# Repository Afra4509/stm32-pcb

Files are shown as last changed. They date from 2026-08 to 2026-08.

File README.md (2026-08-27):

# STM32F103 PCB Design

Repository: https://github.com/Afra4509/stm32-pcb

# Custom STM32F103C8T6 Bare-Chip Development Board

Proyek ini adalah desain custom board berbasis **STM32F103C8T6** yang disolder langsung pada PCB (bare-chip). Desain ini menggunakan template KiCad yang telah dikonfigurasi untuk power delivery, reset circuit, dan external oscillator.

## Fitur Utama Board
- **MCU**: STM32F103C8T6 (LQFP-48)
- **Regulator 3.3V**: LDO (Low Dropout) untuk konversi 5V dari USB/VIN ke 3.3V.
- **Decoupling**: 4x 100nF capacitor diletakkan sedekat mungkin dengan pin VDD, dan 10uF bulk capacitor.
- **Clock**: External Crystal 8MHz (atau 16MHz) + 2x 20pF load capacitors.
- **Bootloader**: Jumper/Switch BOOT0 dengan pull-down 10kΩ.
- **Programming**: 4-pin SWD header (3V3, SWDIO, SWCLK, GND).
- **Konektivitas**: Pin GPIO diekspos melalui header 2.54mm.

### 1. Mengganti USB Micro-B ke USB-C
Secara default, skematik ini menggunakan **USB Micro-B**. Untuk mengubahnya ke **USB-C**:
1. Buka `STM32F103_Custom.kicad_sch` di KiCad.
2. Hapus simbol USB Micro-B.
3. Tambahkan simbol `USB_C_Receptacle_USB2.0`.
4. Hubungkan pin VBUS ke 5V dan GND ke Ground.
5. Tambahkan **dua buah resistor 5.1kΩ**. Hubungkan CC1 ke GND dan CC2 ke GND (wajib agar power 5V keluar dari host).
6. Hubungkan pin D+ ke PA12 dan D- ke PA11. Pastikan Anda memiliki resistor pull-up 1.5kΩ di D+ jika menggunakan skema full-speed USB standar (STM32 tertentu butuh ini).

### 2. Menambahkan User LED
1. Tambahkan komponen LED dan Resistor (misal 1kΩ) pada skematik.
2. Hubungkan pin anoda LED ke 3.3V.
3. Hubungkan pin katoda ke resistor, lalu ke **PC13** pada STM32 (Active Low).
4. Berikan label "USER LED".

### 3. Menambahkan User Button
1. Tambahkan komponen Push Button (SPST).
2. Hubungkan satu sisi ke GND dan sisi lainnya ke **PA0**.
3. Tambahkan resistor pull-up eksternal 10kΩ ke 3.3V pada sisi PA0, atau gunakan pull-up internal MCU.
4. Berikan label "USER BUTTON".

### 4. Layout dan Routing (PCB Editor)
Buka file `STM32F103_Custom.kicad_pcb`:
- **Placement**: Pindahkan konektor USB-C yang baru, LED, dan Button ke tempat yang mudah diakses.
- **Routing**: Rutekan (track) jalur USB-C (D+ dan D- sebagai differential pair), serta jalur GPIO ke LED dan Button.
- **GND Plane**: Board ini menggunakan copper pour untuk GND Plane di layer bawah (B.Cu).
- **Silkscreen**: Tambahkan teks indikator untuk LED, Button, dan pin 3V3/5V/GND di area Silkscreen.

## Aturan Desain (DRC / ERC)
Sebelum mengirimkan ke manufaktur (seperti JLCPCB atau PCBWay):
- Jalankan **ERC (Electrical Rules Checker)** di Schematic Editor untuk memastikan tidak ada net yang melayang (floating).
- Jalankan **DRC (Design Rules Checker)** di PCB Editor.
- Pastikan clearance antara jalur memenuhi standar manufaktur (minimal 0.15mm atau 6 mils).

## Struktur File
- `STM32F103_Custom.kicad_pro` : File proyek utama.
- `STM32F103_Custom.kicad_sch` : File skematik.
- `STM32F103_Custom.kicad_pcb` : File layout PCB.

Terima kasih, dan selamat merakit board STM32 kustom Anda!

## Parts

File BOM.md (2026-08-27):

# Bill of Materials (BOM) - STM32F103 Custom Board

Berikut adalah daftar komponen (BOM) yang disarankan untuk merakit board ini. Anda dapat membeli komponen ini dari supplier seperti LCSC, DigiKey, Mouser, atau Tokopedia.

| Referensi | Komponen / Nilai | Footprint | Deskripsi |
| :--- | :--- | :--- | :--- |
| **U1** | **STM32F103C8T6** | LQFP-48 | Microcontroller ARM Cortex-M3 (Bare-Chip) |
| **U2** | **AMS1117-3.3** atau **AP2112K-3.3** | SOT-223 / SOT-23-5 | LDO Voltage Regulator (5V ke 3.3V) |
| **J1** | **USB-C Receptacle** | 16-pin / 6-pin | Power & Data Input (Data opsional) |
| **Y1** | **Crystal 8MHz** | SMD 5032 / HC49 | High-Speed External Clock (HSE) |
| **C1, C2** | **20pF** | 0603 / 0805 | Load Capacitor untuk Crystal Y1 |
| **C3, C4, C5, C6**| **100nF (0.1µF)** | 0603 / 0805 | Decoupling Capacitor (Dekat VDD/VDDA) |
| **C7** | **100nF (0.1µF)** | 0603 / 0805 | NRST Filter Capacitor |
| **C8, C9** | **10µF** | 0805 / 1206 | Input & Output Bulk Capacitor untuk LDO |
| **R1, R2** | **5.1kΩ** | 0603 / 0805 | Pull-down resistor untuk pin CC1 dan CC2 di USB-C |
| **R3** | **1.5kΩ** | 0603 / 0805 | Pull-up resistor untuk USB D+ (opsional/tergantung desain) |
| **R4, R5** | **10kΩ** | 0603 / 0805 | Pull-down untuk BOOT0 dan Pull-up untuk NRST/Button |
| **R6, R7** | **1kΩ - 2.2kΩ** | 0603 / 0805 | Current Limiting Resistor untuk LED |
| **LED1** | **LED Merah/Hijau** | 0603 / 0805 | Power Indicator LED |
| **LED2** | **LED Biru/Kuning** | 0603 / 0805 | User LED (Terhubung ke PC13) |
| **SW1** | **Push Button (SPST)**| SMD 3x4 / 6x6 | Reset Button |
| **SW2** | **Push Button (SPST)**| SMD 3x4 / 6x6 | User Button (Terhubung ke PA0) |
| **J2** | **Pin Header 1x4** | 2.54mm Pitch | SWD Programming Header (3V3, SWDIO, SWCLK, GND) |
| **J3, J4** | **Pin Header 1x20** | 2.54mm Pitch | GPIO Expansion Header |
| **J5** | **Pin Header 1x3** | 2.54mm Pitch | BOOT0 Selection Jumper |

## Catatan Perakitan
1. **Penyolderan MCU**: Solder IC STM32F103C8T6 terlebih dahulu menggunakan teknik drag soldering atau hot air. Perhatikan orientasi pin 1 (titik pada IC).
2. **Kapasitor Decoupling**: Tempatkan C3-C6 (100nF) sangat dekat dengan pin VDD dan VSS pada IC STM32.
3. **USB-C**: Jika Anda menyolder secara manual, pastikan tidak ada bridge (korsleting) antara pin VBUS, GND, dan D+/D-. Gunakan flux yang cukup.

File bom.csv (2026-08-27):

Designator | Footprint | Quantity | Value | LCSC Part #
BOOT | SW_SPDT_PCM12 | 1 | SW_SPDT | C221841
C1, C2, C3, C4, C9 | 402 | 5 | 100n | C77020
C10, C11 | 402 | 2 | 10p | C76946
C12, C13 | 805 | 2 | 22u | C602037
C5 | 603 | 1 | 10u | C19702
C6 | 402 | 1 | 10n | C15195
C7, C8 | 402 | 2 | 1u | C14445
FB1 | 603 | 1 | 120R | C14709
J2, J3, J4, J5 | PinHeader_1x04_P2.54mm_Vertical | 4 | Conn_01x04_Pin | C2691448
ON | 603 | 1 | RED | C965799
R1 | 402 | 1 | 10k | C60490
R2, R3, R4, R5 | 402 | 4 | 1k5 | C114759
U1 | LQFP-48_7x7mm_P0.5mm | 1 | STM32F103C8T6 | C8734
U2 | SOT-223-3_TabPin2 | 1 | AMS1117-3.3 | C347222
USB | USB_Micro-B_Wuerth_629105150521 | 1 | USB_B_Micro | C505111
Y1 | Crystal_SMD_3225-4Pin_3.2x2.5mm | 1 | 16MHz | C127500

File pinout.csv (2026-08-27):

Position | Name | Type | Signal | Label
1 | VBAT | Power
2 | PC13-TAMPER-RTC | I/O
3 | PC14-OSC32_IN | I/O
4 | PC15-OSC32_OUT | I/O
5 | PD0-OSC_IN | I/O | RCC_OSC_IN
6 | PD1-OSC_OUT | I/O | RCC_OSC_OUT
7 | NRST | Reset
8 | VSSA | Power
9 | VDDA | Power
10 | PA0-WKUP | I/O
11 | PA1 | I/O
12 | PA2 | I/O
13 | PA3 | I/O
14 | PA4 | I/O
15 | PA5 | I/O
16 | PA6 | I/O
17 | PA7 | I/O
18 | PB0 | I/O
19 | PB1 | I/O
20 | PB2 | I/O
21 | PB10 | I/O | I2C2_SCL
22 | PB11 | I/O | I2C2_SDA
23 | VSS | Power
24 | VDD | Power
25 | PB12 | I/O
26 | PB13 | I/O
27 | PB14 | I/O
28 | PB15 | I/O
29 | PA8 | I/O
30 | PA9 | I/O
31 | PA10 | I/O
32 | PA11 | I/O | USB_DM
33 | PA12 | I/O | USB_DP
34 | PA13 | I/O | SYS_JTMS-SWDIO
35 | VSS | Power
36 | VDD | Power
37 | PA14 | I/O | SYS_JTCK-SWCLK
38 | PA15 | I/O
39 | PB3 | I/O
40 | PB4 | I/O
41 | PB5 | I/O
42 | PB6 | I/O | USART1_TX
43 | PB7 | I/O | USART1_RX
44 | BOOT0 | Boot
45 | PB8 | I/O
46 | PB9 | I/O
47 | VSS | Power
48 | VDD | Power

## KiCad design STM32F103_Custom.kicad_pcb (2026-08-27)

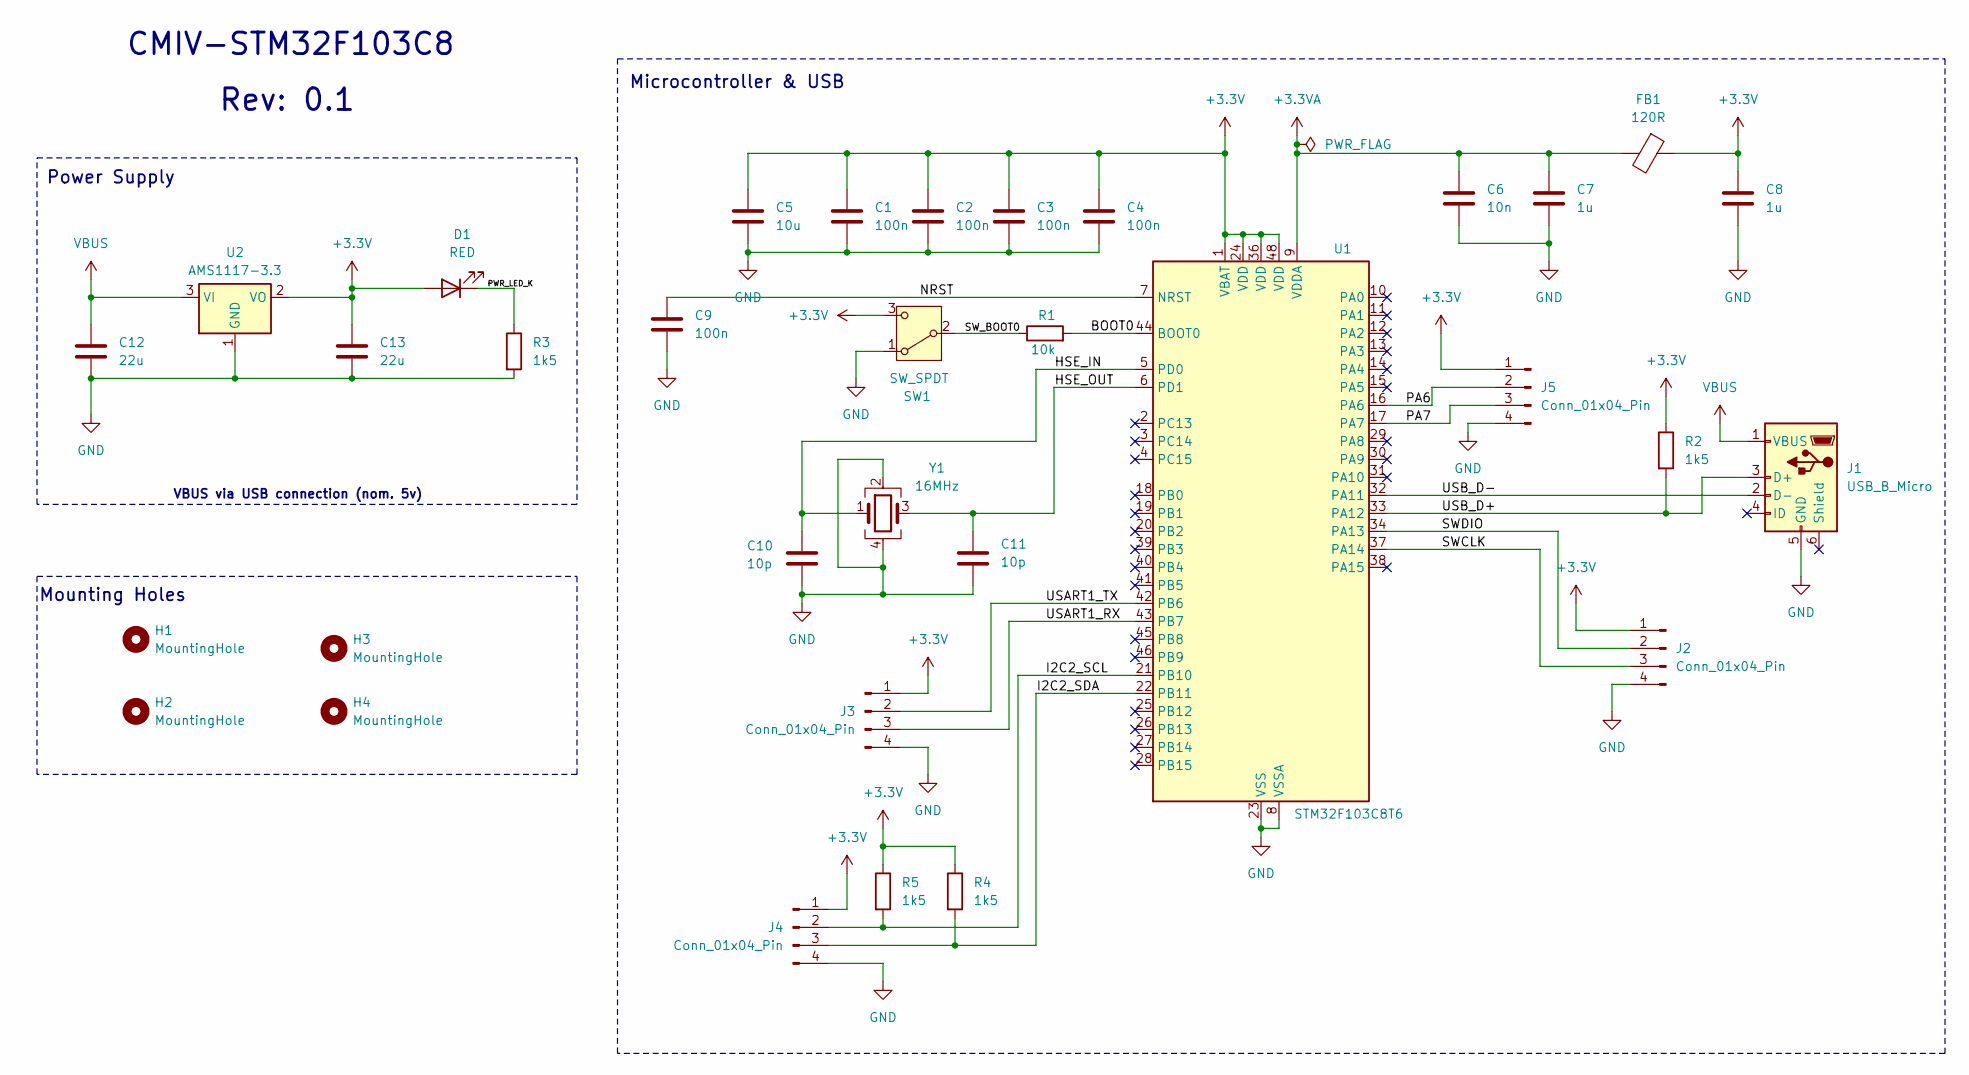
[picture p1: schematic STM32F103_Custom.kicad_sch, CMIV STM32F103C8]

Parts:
C1, C2, C3, C4, C9: 100n; C_0402_1005Metric
C5: 10u; C_0603_1608Metric
C6: 10n; C_0402_1005Metric
C7, C8: 1u; C_0402_1005Metric
C10, C11: 10p; C_0402_1005Metric
C12, C13: 22u; C_0805_2012Metric
D1: RED; LED_0603_1608Metric
FB1: 120R; L_0603_1608Metric
H1, H2, H3, H4: MountingHole; MountingHole_2.2mm_M2
J1: USB_B_Micro; USB_Micro-B_XKB_U254-051T-4BH83-F1S
J2, J3, J4, J5: Conn_01x04_Pin; PinHeader_1x04_P2.54mm_Vertical
R1: 10k; R_0402_1005Metric
R2, R3, R4, R5: 1k5; R_0402_1005Metric
SW1: SW_SPDT; SW_SPDT_PCM12
U1: STM32F103C8T6; LQFP-48_7x7mm_P0.5mm
U2: AMS1117-3.3; SOT-223-3_TabPin2
Y1: 16MHz; Crystal_SMD_3225-4Pin_3.2x2.5mm

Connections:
+3.3V: C1.1, C2.1, C3.1, C4.1, C5.1, C8.1, C13.1, D1.2 (A), FB1.1, J2.1, J3.1, J4.1, J5.1, R2.1, R4.1, R5.1, SW1.3 (C), U1.1 (VBAT), U1.24 (VDD), U1.36 (VDD), U1.48 (VDD), U2.2 (VO); also elsewhere on the board
+3.3VA: C6.1, C7.1, FB1.2, U1.9 (VDDA)
/BOOT0: R1.2, U1.44 (BOOT0)
/HSE_IN: C10.1, U1.5 (PD0), Y1.1
/HSE_OUT: C11.1, U1.6 (PD1), Y1.3
/I2C2_SCL: J4.2, R5.2, U1.21 (PB10)
/I2C2_SDA: J4.3, R4.2, U1.22 (PB11)
/NRST: C9.1, U1.7 (NRST)
/PA6: J5.2, U1.16 (PA6)
/PA7: J5.3, U1.17 (PA7)
/PWR_LED_K: D1.1 (K), R3.1
/SWCLK: J2.3, U1.37 (PA14)
/SWDIO: J2.2, U1.34 (PA13)
/SW_BOOT0: R1.1, SW1.2 (B); also elsewhere on the board
/USART1_RX: J3.3, U1.43 (PB7)
/USART1_TX: J3.2, U1.42 (PB6)
/USB_D+: J1.3 (D+), R2.2, U1.33 (PA12); also elsewhere on the board
/USB_D-: J1.2 (D-), U1.32 (PA11); also elsewhere on the board
GND: C1.2, C2.2, C3.2, C4.2, C5.2, C6.2, C7.2, C8.2, C9.2, C10.2, C11.2, C12.2, C13.2, J1.5 (GND), J2.4, J3.4, J4.4, J5.4, R3.2, SW1.1 (A), U1.8 (VSSA), U1.23 (VSS), U1.35 (VSS), U1.47 (VSS), U2.1 (GND), Y1.2, Y1.4; also elsewhere on the board
VBUS: C12.1, J1.1 (VBUS), U2.3 (VI); also elsewhere on the board

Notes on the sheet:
Rev: 0.1
Power Supply
VBUS via USB connection (nom. 5v)
Mounting Holes
CMIV-STM32F103C8
Microcontroller & USB

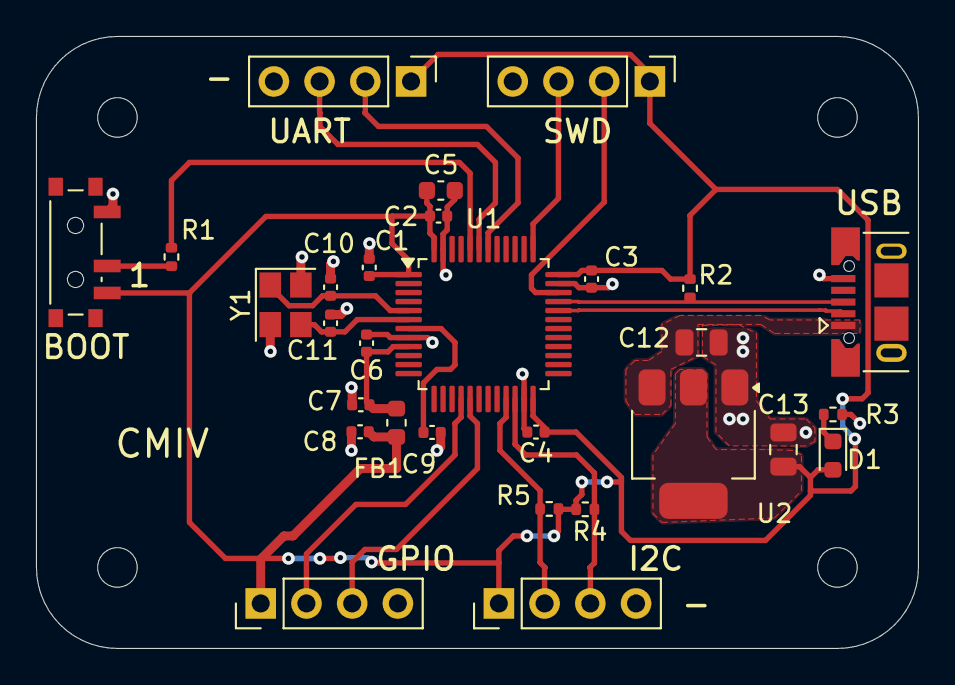
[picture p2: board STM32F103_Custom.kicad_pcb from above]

Board: 2 copper layers, 49.0 x 34.0 mm, 33 parts (0 on the bottom side), 20 nets.

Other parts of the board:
BOOT: SW_SPDT; SW_SPDT_PCM12
USB: USB_B_Micro; USB_Micro-B_XKB_U254-051T-4BH83-F1S

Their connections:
+3.3V: BOOT.3 (C); also elsewhere on the board
/SW_BOOT0: BOOT.2 (B); also elsewhere on the board
/USB_D+: USB.3 (D+); also elsewhere on the board
/USB_D-: USB.2 (D-); also elsewhere on the board
GND: BOOT.1 (A), USB.5 (GND); also elsewhere on the board
VBUS: USB.1 (VBUS); also elsewhere on the board
